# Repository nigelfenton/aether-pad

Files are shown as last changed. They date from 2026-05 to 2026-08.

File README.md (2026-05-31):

# aether_pad

A standalone hardware control surface for [AetherSDR](https://github.com/ten9876/AetherSDR), built on an Arduino Giga R1 WiFi + Display Shield. One self-contained box gives you VFO tuning, mode/volume/band quick-control via a touchscreen, and a CW iambic keyer — all talking to AetherSDR over its TCI WebSocket.

Ops by **G0JKN / W3**.

## Gallery

| Boot — persona menu | Running — TCI persona |
|---|---|
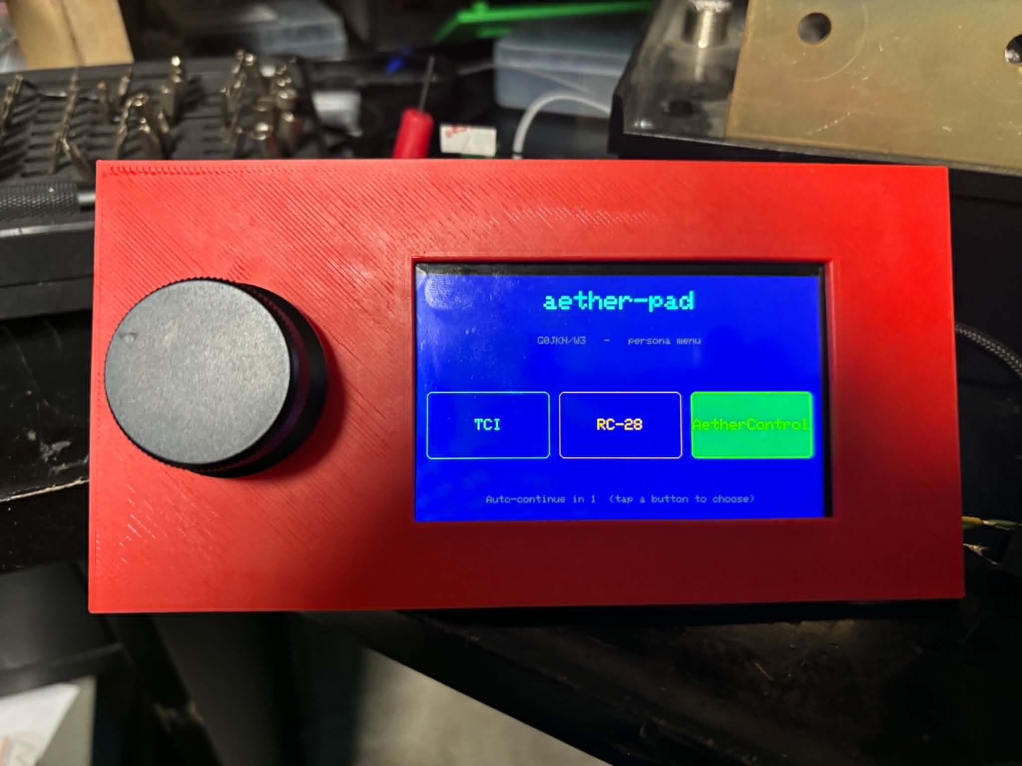
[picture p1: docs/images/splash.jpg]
Splash / persona menu
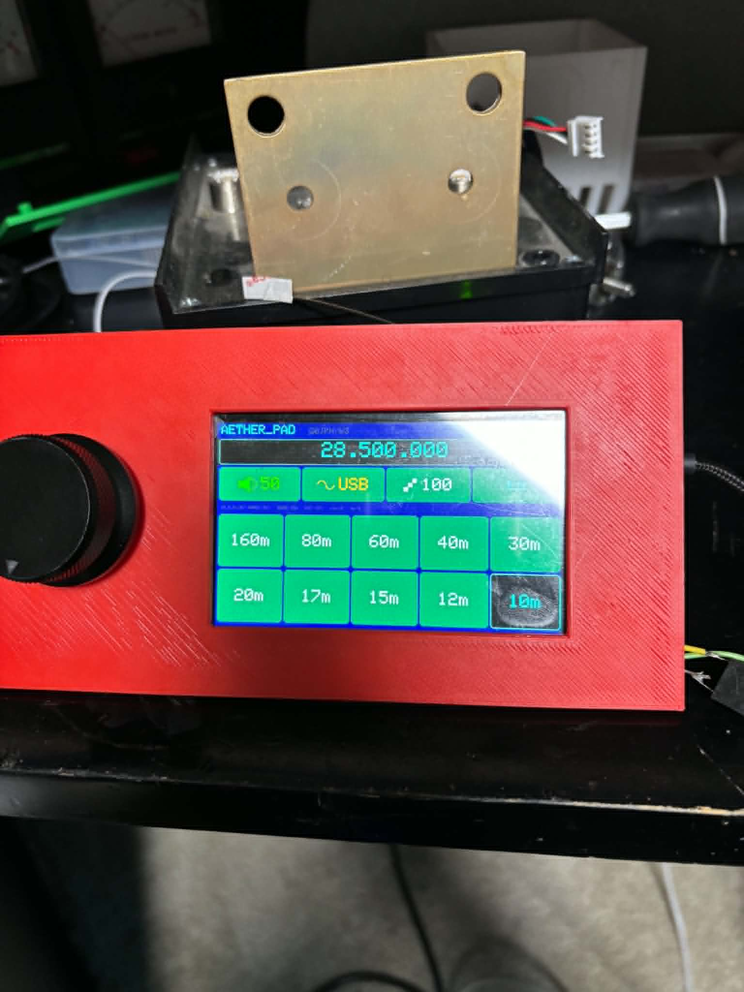
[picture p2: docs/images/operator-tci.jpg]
TCI operator screen on 10 m USB
|  |  |
| Three-button splash (TCI / RC-28 / AetherControl) with 3 s auto-continue. Tap the title bar on any operator screen to re-open this menu. | TCI persona running against AetherSDR — 28.500.000 MHz USB, 10 m band selected. Modal chips arm the encoder for volume / mode / step / keyer in turn. |

## Features

- **Auto-discovery** of AetherSDR on the LAN (UDP probe → unicast reply on port 40002)
- **TCI WebSocket** client — hand-rolled framing, no external libraries beyond stock Arduino WiFi / Display
- **Optical encoder** for VFO tuning with software divider and configurable Hz/click
- **8-button touchscreen** (2 × 4 grid) for VOL / BAND / MODE / VFO ± controls
- **CW iambic keyer** (Mode A or B) — paddles on a 3.5 mm jack, drives the radio's key line through a **GPIO output (D6)** for sub-microsecond, jitter-free timing.  Optional TCI echo (`keyer:0,true|false;`) can be enabled at compile time for AetherSDR-side UI awareness.
- Live status display on the 800 × 480 panel: frequency, mode, volume, band, encoder diagnostics
- Falls back to a hardcoded host IP if discovery times out — works against vanilla AetherSDR (≥ v0.9.5.1) once the responder patch lands

## Hardware

| Part | Notes |
|---|---|
| Arduino Giga R1 WiFi | STM32H747, dual-core M7+M4, USB-C |
| Arduino Giga Display Shield | 800 × 480 panel, GT911 capacitive touch |
| Optical rotary encoder | **LPD3806-600BM-G5-24C** (600 PPR, NPN open-collector, 5–24 V) — runs off Giga 5 V. Autonics E50S-360B (360 PPR, 12–24 V) is also supported as a compile-time alternate via `#define ENCODER_AUTONICS_E50S` near the top of the sketch. |
| 2 × **10 kΩ** resistors | Pull-ups for encoder A (D2) and B (D3) to **3.3 V — never 5 V**. **Required**, not optional — the Giga's internal `INPUT_PULLUP` is too weak to firmly pull these lines HIGH between transistor pulses. |
| Optional: 2 × 10 kΩ resistors | Paddle pull-ups for D4/D5 to 3.3 V if you see noise on long paddle cables. The internal `INPUT_PULLUP` is fine for short paddle leads since a paddle is a passive switch (no leakage current). |
| Optional: 2 × 100 pF caps | D2 / D3 to GND, additional EMI filtering |
| 3.5 mm stereo TRS jack | CW iambic paddle input (or straight key — tip + sleeve only) |
| Encoder supply | 5 V from the Giga **5V** pin if using LPD3806; external 13.8 V (shack rail) if using Autonics E50S — its LED will not light below 12 V |

## Wiring

```
                  Giga R1 WiFi (with Display Shield)
                  ┌─────────────────────────────────┐
                  │                                 │
       Encoder    │                                 │
       ┌────┐     │                                 │
       │ +V ├──── 5 V  (LPD3806 — Giga 5V pin)      │
       │    │     or 13.8 V (Autonics E50S only)    │
       │ 0V ├──── GND ────────── share with Giga    │
       │ A  ├──── D2  (10 kΩ pull-up to 3.3 V)      │
       │ B  ├──── D3  (10 kΩ pull-up to 3.3 V)      │
       └────┘     │                                 │
                  │   pull-ups go to 3.3 V, NEVER   │
                  │   5 V — Giga inputs aren't 5 V  │
                  │   tolerant                      │
                  │                                 │
       Paddle     │                                 │
       (3.5 mm    │                                 │
        TRS)      │                                 │
       ┌────┐     │                                 │
       │ tip├──── D4   (INPUT_PULLUP, dit)          │
       │ rng├──── D5   (INPUT_PULLUP, dah)          │
       │ slv├──── GND                               │
       └────┘     │                                 │
                  │   (straight-key mode discussed, │
                  │   not yet in firmware — for now │
                  │   the iambic state machine will │
                  │   try to interpret a held key)  │
                  │                                 │
       Radio key  │                                 │
                  ├──── D6 → NPN or opto buffer     │
                  │     → radio CW key jack         │
                  │     (see "CW key output" below) │
                  └─────────────────────────────────┘
```

Touch transform `tx = raw_y, ty = 479 - raw_x` is verified for landscape mounting (long axis horizontal, USB-C on the right). If you mount differently, run `tm 0..3` over serial to flip.

## Network

- **WiFi SSID/pass** is hardcoded near the top of `aether_pad.ino` (`tinkerbell` by default — change to your shack network).
- **Discovery** broadcasts `AETHERPAD?` on the local /24 subnet, UDP port 40002. AetherSDR ≥ v0.9.5.1 (with the [TciServer responder patch](https://github.com/nigelfenton/AetherSDR)) replies unicast `AETHERSDR ip=<addr> tci=<port>`.
- **Fallback** after 5 s without a reply: `10.0.0.107:40001`. Override at runtime with `ip <addr>` over serial.

## Install — build and flash the firmware

You'll need an Arduino Giga R1 WiFi, a USB-C cable, and the Display
Shield mounted. Everything below runs in the **Arduino IDE** — no
command-line compiler to wrestle with.

### 1. Install Arduino IDE

Download **Arduino IDE 2.x** from <https://www.arduino.cc/en/software>
and run the installer (Windows / macOS / Linux all supported).

### 2. Add Giga R1 board support

In the IDE:

1. **Tools → Board → Boards Manager…**
2. Search for **`Mbed OS Giga`**
3. Install **Arduino Mbed OS Giga Boards** (latest version)

The board package pulls in the Display Shield libraries automatically:

- `Arduino_H7_Video`
- `Arduino_GigaDisplay_GFX`
- `Arduino_GigaDisplayTouch`

If any are missing, install them via **Sketch → Include Library → Manage Libraries…**

> **⚠️ Pin `Arduino_GigaDisplay_GFX` to 1.0.0.** Version **1.1.0** produces a
> **black screen** — the firmware runs fine (WiFi/TCI all work), but the display
> init breaks against the stable Mbed Giga core's bundled `Arduino_H7_Video` 1.0.
> In **Manage Libraries**, pick **1.0.0** from the version dropdown. If "Update all
> libraries" ever bumps it to 1.1.0, just roll it back to 1.0.0 and re-flash.

### 3. Download the firmware

Either clone the repo:

```sh
git clone https://github.com/nigelfenton/aether-pad.git
```

…or click the green **Code → Download ZIP** button at the top of this
page and unzip it.

### 4. Set your WiFi credentials

Open `aether_pad.ino` in the IDE and edit the two lines near the top:

```cpp
#define WIFI_SSID  "your-network"
#define WIFI_PASS  "your-password"
```

The Giga's WiFi radio is **2.4 GHz only** — point it at your 2.4 GHz SSID,
not a 5 GHz one.

### 5. Plug in the Giga R1

Connect the Giga to your computer with the USB-C cable. After a few
seconds it should appear as a new serial port.

### 6. Pick the board and port

- **Tools → Board → Arduino Mbed OS Giga Boards → Arduino Giga R1**
- **Tools → Port → *<the new port that just appeared>***
  - Windows: typically `COM4` / `COM5` / etc.
  - macOS: `/dev/cu.usbmodem…`
  - Linux: `/dev/ttyACM0`

### 7. Upload

Click the **→** Upload button (top-left of the IDE window). The first
flash takes 1–2 minutes — subsequent ones are quicker. Watch for
**"Done uploading."** at the bottom of the IDE.

### 8. Confirm it booted

Open **Tools → Serial Monitor** and set the baud rate to **115200**
(dropdown bottom-right of the Monitor window). You should see something
like:

```
aether_pad — booting
Build: <date> <time>
WiFi: ........
WiFi connected, IP = 10.0.0.220
Discovery probe → 10.0.0.255
Discovery reply: AETHERSDR ip=10.0.0.107 tci=40001
AetherSDR @ 10.0.0.107:40001
TCI: connecting to 10.0.0.107:40001
TCI: WebSocket handshake OK
```

The touchscreen will light up showing frequency / mode / volume cards
once TCI is connected.

### Troubleshooting

- **No port shows under Tools → Port.** Try a different USB-C cable —
  some are charge-only and carry no data. Unplug, replug, restart the
  IDE if needed.
- **"Board not in selected port" / upload fails.** Double-press the
  Giga's small reset button to force USB bootloader mode, then re-select
  the new port (it will change) and Upload again.
- **WiFi never connects.** Double-check SSID/password spelling. Confirm
  you're on the 2.4 GHz SSID, not 5 GHz.
- **TCI never connects.** In AetherSDR, open **Tools → TCI** and make
  sure the TCI server is enabled on port **40001**. The Giga and the
  AetherSDR host need to be on the same LAN.

## Operating

### Encoder
Spin the knob to tune the VFO. Default step is **100 Hz/click** (fine SSB tuning). Change with `step N` over serial — common values: `step 10`, `step 100`, `step 1000`, `step 10000`. The same step value is shared with the on-screen VFO± buttons.

### Touch buttons (2 × 4 grid)

| Top row | Bottom row |
|---|---|
| `VOL+`  (+5 %) | `VOL−`  (−5 %) |
| `BAND+` (next ham band)¹ | `BAND−` (previous)¹ |
| `MODE+` (next mode in `am sam dsb lsb usb cw digl digu fm dfm spec rtty`) | `MODE−` |
| `VFO+`  (step by current `step`) | `VFO−` (step by current `step`) |

**Long press** (~600 ms) on `VFO+` or `VFO−` cycles the step size:
**100 Hz → 1 kHz → 10 kHz → 100 kHz → wrap.** The current value is shown in the **STEP** card, and the encoder uses the same value, so spinning the knob and tapping the VFO buttons always agree.

¹ *Status note (2026-05-04):* AetherSDR's TCI server doesn't currently implement `band_up`/`band_down` commands, so the BAND± buttons do nothing. Tracked as a known issue.

### CW iambic keyer
Squeeze paddles, send dits/dahs.  Default 25 WPM, Iambic Mode B.  Adjust with `wpm N` and `iambic A|B` over serial.  The Giga handles all element timing in software and drives the radio's key line directly via **D6** — TCI is bypassed entirely for the timing-critical wire path because WebSocket-over-WiFi latency and jitter made dit/dah length audibly unstable even at modest speeds.

> **Optional TCI echo:** if you want AetherSDR to also see the key events for sidetone / UI / metering purposes, define `KEYER_TCI_ECHO 1` at the top of the sketch (or set `-DKEYER_TCI_ECHO=1` at compile time).  The hardware key line is still authoritative for actual radio keying — TCI just gets informational copies.

### CW key output (D6 — default since v0.2)

D6 goes HIGH on key-down and LOW on key-up.  Wire a small buffer between D6 and the radio's CW key jack — never connect the Giga GPIO directly to a key line, since some radios bias the line to +12 V or higher.  Two interface options depending on how isolated you want the Giga from the radio:

Two hardware options depending on how isolated you want the Giga from the radio:

#### Option 1 — NPN buffer (simple, ~£0.10)

Fine for modern transceivers with safe key-line voltages (typically 3–15 V open-circuit, low current). Shares ground with the radio.

```
                                        ┌──────── Radio KEY tip
   Giga D6 ──[ 1 kΩ ]── B (NPN)         │
                        │                C
                        │           ┌────┴────┐
                        E ── GND ───┤   NPN   │
                        (Giga)      │  BC547  │
                                    │ 2N3904  │
                                    │ 2N2222  │
                                    └─────────┘
                                         E ──── GND (shared with radio)
```

- **D6 HIGH** → transistor ON → key line pulled to ground = **key down**
- **D6 LOW**  → transistor OFF → key line floats = **key up**
- Optional 10 kΩ from base to emitter keeps the transistor firmly OFF if D6 ever goes high-impedance.

#### Option 2 — Opto-isolator (proper galvanic isolation, ~£0.50)

Recommended if you're keying a high-power amplifier directly, a tube rig where the key line could float at +30 V or more, or you've ever seen ground-loop or RF-induced weirdness in the shack. The Giga and radio share **no** ground.

```
                                ┌────────── Radio KEY tip
   Giga D6 ──[ 330 Ω ]── A      │
                         │      C
                         │ ┌────┴────┐
                         K │  4N35   │
                         │ │  PC817  │
                         │ │  4N25   │
                         │ └────┬────┘
                         GND    E ──── Radio GND (NOT Giga GND)
                        (Giga)
```

#### Firmware

The keyer's wire path lives in a single `keyerOutput()` function in `aether_pad.ino`.  Default behaviour (since v0.2) is GPIO-only:

```cpp
void keyerOutput(bool down) {
    if (kr.keyDown == down) return;
    kr.keyDown = down;
    digitalWrite(KEY_PIN_OUT, down ? HIGH : LOW);
#if KEYER_TCI_ECHO
    wsSendText(down ? "keyer:0,true;" : "keyer:0,false;");
#endif
    if (down) kr.txCount++;
    uiNeedsRedraw = true;
}
```

The state machine is fully decoupled from the wire — to add MIDI keying, a second hardware output, or anything else, edit only this function.

## Serial commands

All commands at **115200 8-N-1**.

| Command | Effect |
|---|---|
| `?` | Print full state (WiFi/TCI/freq/mode/vol/band/encoder/keyer) |
| `ip <a.b.c.d>` | Override AetherSDR IP and force reconnect |
| `freq <Hz>` | Tune VFO directly |
| `step <Hz>` | Set the shared step size (10 / 100 / 1000 / 10000 typical). Used by both the encoder and the on-screen VFO± buttons. |
| `vol <0..100>` | Set volume directly (AetherSDR audioGain percent — *not* dB) |
| `div <N>` | Set encoder divider (raw quadrature counts per emitted step). Defaults: **40** for LPD3806, **24** for Autonics E50S. |
| `tm 0..3` | Touch transform: 0 = default (verified), 1 = 180°, 2 = raw, 3 = flip-both |
| `wpm <5..100>` | CW keyer speed |
| `iambic A\|B` | Iambic mode (A = current-element-only / no memory; B = opposite-paddle memory, default) |

## Architecture

```
┌─────────────┐  WiFi (UDP 40002)  ┌──────────┐
│  aether_pad ├───── discovery ───►│          │
│   (Giga)    │◄──── reply ────────┤          │
│             │                    │ AetherSDR│
│             │   WS TCI :40001    │          │
│             ├────────────────────►          │
│             │◄────── echoes ─────┤          │
└─┬─┬─┬─┬─────┘                    └──────────┘
  │ │ │ └── touchscreen UI (display + 8 buttons)
  │ │ └──── optical encoder (D2/D3, INT-driven, quadrature)
  │ └────── CW paddle (D4/D5, polled, iambic state machine)
  └──────── serial console (115200, debug + control)
```

The TCI client is hand-rolled WebSocket framing over `WiFiClient`, same minimal approach as [ShackController](https://github.com/nigelfenton/shackcontroller). Outbound frames: `0x81 [len] [payload]` (FIN + text, unmasked — AetherSDR is permissive). Inbound parser handles both masked and unmasked text frames; close frame triggers reconnect. No external WebSocket library needed.

## File map

```
aether_pad/
├── aether_pad.ino       ← all firmware, single sketch
├── README.md            ← this file
├── CASE_DIMENSIONS.md   ← physical case build notes
├── CASE_DIMENSIONS.pdf  ← rendered version of the above
├── md_to_pdf.py         ← helper to regenerate the PDF
├── Aether pad.step      ← Fusion-exported 3D model of the front panel
├── Aether pad.stl       ← latest STL for the slicer
└── lpd3806_panel.dxf    ← 2D sketch of the encoder cutouts (boss + 30 mm PCD)
```

## Future work

- Memory keyer (preprogrammed CQ / 73 / name+QTH macros via `cw_msg:` or `cw_macros:`)
- On-device WPM adjustment via touch (long-press an existing button to enter "CW mode")
- Web UI on port 80 (HTML scaffold is dormant in the source — about 50 lines from working)
- Migrate keyer tick to a hardware timer ISR if loop jitter affects element edges

## Licence

Same as the rest of `shack-experiments` — pick whatever G0JKN's repo licence is.

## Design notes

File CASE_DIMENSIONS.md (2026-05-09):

# aether_pad — case dimensions reference

Single-source dimensional data for designing the Fusion 360 case.
**Verify critical dimensions with calipers before committing extrusions** —
some values below are from datasheets/typicals and may differ slightly from
the actual hardware on your bench.

## 1. Arduino Giga R1 WiFi (base board)

| Property | Value |
|---|---|
| PCB outline | 101.52 × 53.3 mm |
| PCB thickness | 1.6 mm |
| Form factor | Arduino Mega-compatible footprint |
| Mounting holes | 4 × M3 (Mega-compatible) — **NOT used in this build** (Giga hangs from Shield via stacked headers) |
| USB-C connector | top edge (long side), centred near corner |
| Power jack | top edge, barrel 2.1mm centre-positive (5.5mm OD), accepts 7-24 V |
| Headers | 4 stacks (digital, analog, power, SDA/SCL) — 8.5 mm tall |
| Stack height to shield top of headers | ~14 mm above PCB |

**Verify:** mounting hole XY positions relative to PCB corner (0,0).

## 2. Giga Display Shield (mates on top of Giga)

| Property | Value |
|---|---|
| Shield PCB outline | **106 × 80 mm** (measured 2026-05-03) |
| Display module (LCD + cover glass, visible extent) | **100 × 58 mm** (measured 2026-05-03) |
| Active pixel area | 84 × 50.5 mm (800 × 480 px, 5:3 aspect, inside the display module) |
| Active display offset from PCB **left edge** | **6.3 mm** (measured) |
| Active display offset from PCB **right edge** | 15.7 mm (computed: 106 − 6.3 − 84) |
| Active display offset from PCB **top edge** | **16 mm** (measured 2026-05-03) |
| Active display offset from PCB **bottom edge** | **13 mm** (measured 2026-05-03) |
| Active display height (computed) | 51 mm (80 − 16 − 13, matches 50.5 mm spec) |
| Vertical bias of active within PCB | ~1.5 mm **toward the bottom** |
| Mounting holes | 4 corners, M3, **5 × 5 mm inset** from each PCB edge (measured) |
| **Mounting hole pattern (centre-to-centre)** | **96 × 70 mm** — these are the only case mounting bosses needed |
| **Front-panel window cutout** | **100 × 58 mm** to expose the full display module |
| USB-C connector (on shield) | edge OPPOSITE the 6.3 mm-margin side (right edge in default orientation) |
| Total stack height (Giga + headers + shield) | ~22 mm from Giga PCB bottom to shield top surface |

**IMPORTANT for assembly:** mount the shield so its **6.3 mm-margin edge faces the encoder**. The opposite edge has 15.7 mm of dead PCB beyond the active area, and orienting that side toward the encoder would cost ~9.4 mm of clearance. The flip-mode rotation preserves this — when the top rotates 180°, the 6.3 mm edge still faces the (now opposite-side) knob.

## 3. Autonics E50S8G5-360B-G24N optical encoder

| Property | Value |
|---|---|
| Body diameter | 50 mm |
| Body length (behind panel) | **38.6 mm** (measured 2026-05-03) |
| Total length incl. shaft | ~52 mm |
| Shaft diameter | 8 mm |
| Shaft length | ~13 mm beyond body |
| Mounting | 3 × M3 screws on a **40 mm PCD** (20 mm radius), on the front face — measured |
| Panel mount hole | 32 mm centre clearance (to clear shaft + boss) |
| Wiring | 5-wire pigtail: A, B, Z, +V (12-24V), 0V |
| Operating voltage | 12-24 V DC (uses 13.8 V from shack rail) |
| PPR | 360 |

**For the recessed-knob design:**
- Panel cutout: 32 mm hole for shaft + boss, 3 × M3 tapped or clearance holes on **40 mm PCD**
- Behind-panel clearance needed: **38.6 mm minimum depth** (encoder body length), 50+ mm diameter
- Knob hollow cavity: 52 mm ID, 38.6+ mm deep so it clears the encoder body
- Knob outer dimensions: ~55-60 mm OD typical, 10-15 mm tall above panel
- Knob coupling: 8 mm bore, M3 grub screw onto shaft flat

## 4. CW paddle jack — 3.5 mm TRS, panel mount

| Property | Value |
|---|---|
| Panel hole | 6 mm |
| Body length behind panel | ~15-20 mm (varies by part) |
| Mounting | nut + lock washer on threaded barrel |
| Wiring | tip = dit (D4), ring = dah (D5), sleeve = GND |

## 5. Power entry — **Anderson PowerPole, daisy-chainable**

12 VDC in via Anderson PowerPoles. **Two pairs** (red+black, red+black) on the
rear panel — one pair is the feed in, the second pair allows daisy-chaining the
next shack module on the same supply. Dimensions confirmed against the parts on
hand.

| Property | Value |
|---|---|
| Housing size (single PP15/30/45) | 7.87 × 11.94 × 16.26 mm |
| Red+black pair (clipped together) | 15.75 × 11.94 × 16.26 mm |
| **Cutout per pair** | **16.3 × 18.4 mm** (snug fit on housing, ~2.7 mm clearance for retainer wall) |
| **Retainer sleeve** | **24.6 mm long, 3 mm wall thickness** around the opening — 3D-printed, extends into the case interior |
| Total clearance behind panel | ~25 mm for housing + wire bend |
| Wiring | Wire both pairs in parallel internally (same +/− nodes) so daisy-chain just passes through |

Encoder needs 12-24 V (uses 13.8 V from shack rail); Giga accepts 7-24 V. Single 12 V supply works for both.

**Cutout layout — TBD, two options:**
- **(a)** Two separate 16.3 × 18.4 cutouts with 5-10 mm gap between → flexible, two independent retainers
- **(b)** One combined 16.3 × ~37.3 mm cutout → single retainer block, more compact

Place on rear panel, central horizontally, ~10 mm up from the case base for cable clearance.

## 6. Combined stack — case envelope (symmetric flip-mode, locked)

Sloped desktop unit, screen on the right of the front panel, encoder + recessed
knob on the left, no side cutouts (no USB-C side access — open the case for
reflashing using a USB-C extension cable).

```
       ┌────────────────────────────────────────┐
      ╱                                         ╲      ← front panel plane
     ╱   ⬡        ┌──────────────────┐         ╲    (sloped 10-15° back)
    ╱   knob      │   Display 84×50  │   15mm  ╲
   ╱   recess     │   active area    │   margin ╲
  ╱   (left)      └──────────────────┘           ╲
 └────────────────────────────────────────────────┘   ← base
        │←──────── ~175 mm total width ────────→│
```

Symmetric design — knob and screen window mirror about the case centreline.
Hardware (Giga + Shield + encoder) lives in the **removable top half**, so
rotating the top 180° physically moves them to the opposite side; the base
stays put with rear connectors fixed in position.

**Front panel layout (default orientation, encoder on left):**

```
 ┌────────────────────────────────────────────────────────┐
 │                                                        │
 │  ┌──────┐                          ┌─────────────────┐ │
 │  │      │                          │                 │ │
 │  │ knob │←────── 20 mm gap ────→│  display window │ │
 │  │ Ø60  │                          │   100 × 58 mm   │ │
 │  │      │                          │                 │ │
 │  └──────┘                          └─────────────────┘ │
 │                                                        │
 └────────────────────────────────────────────────────────┘
   │←15→│←──60──→│←─── 20 ───→│←────── 100 ──────→│←15→│
   │←──── 60 ────→│             │←──── 100 ────→│
   │  knob centre at -60       │ window centre at +40
   │←──────────── 210 mm internal ────────────→│
```

| Property | Value |
|---|---|
| Margin: knob outer edge to left wall | 15 mm |
| Margin: window outer edge to right wall | 15 mm |
| Gap between knob and window | **20 mm** (gives 26.7 mm encoder-PCB clearance) |
| Knob centre offset from case centreline | 60 mm (left in default) |
| Window centre offset from case centreline | 40 mm (right in default) |
| Top + bottom margins to window | **17 mm** each (gives ~5 mm PCB clearance) |

**Internal envelope (locked):**

| Dimension | Value | Driver |
|---|---|---|
| Width  | **210 mm** | symmetric about centreline, 60+30+15 each side, 20 gap, screen window 100 |
| Height (perp to slope) | **92 mm** | window 58 + 17 top + 17 bottom margins (PCB ~5 mm clearance) |
| **Slope angle from vertical** | **15°** | nearly upright, compact, comfortable bench viewing |
| **Total interior depth (front to back at base)** | **68.8 mm** | wedge 23.8 + box 45 (box bumped to clear deeper-than-spec encoder body) |
| **Total interior height (vertical)** | **88.9 mm** | = 92 × cos(15°) |

**Side profile (right trapezoid, looking from the right):**

```
       A─────────────────────────────B    A = (23.8, 88.9) — wedge top
      ╱│                             │    B = (68.8, 88.9) — back top
     ╱ │                             │    C = (68.8, 0)    — back bottom
    ╱  │        case                 │    D = (0, 0)       — front bottom
   ╱   │        interior             │
  ╱    │                             │    Slope D→A: 92 mm @ 15° from vertical
 ╱     │                             │    Top   A→B: 45 mm flat (box top)
╱      │                             │    Back  B→C: 88.9 mm vertical
└──────┴─────────────────────────────┘    Base  C→D: 68.8 mm horizontal
       ←── 23.8 ──→←──── 45 ────→
        wedge       box
```

External envelope with 3 mm walls: **216 W × 75 D × 95 H mm**.

**Component placement inside (verified, no 3D conflicts):**

| Component | Front-face / mount position | Extent into case |
|---|---|---|
| Display Shield + Giga stack | parallel to slope, mounted to fascia | 22 mm perpendicular to slope |
| Encoder body | slope midpoint (X=11.9, Y=44.4), Z=−60 from centreline | 38.6 mm along slope normal → back face at (X=49.2, Y=34.4); back-top corner at (X=55.7, Y=58.6) |
| PowerPole sleeves (×2) | back wall, centred Z, centred Y | 24.6 mm into case (X from 44.2 to 68.8) |
| Paddle jack | back wall, centred Z | ~15-20 mm sleeve |
| Flip switch | back wall, near corner | tiny |

The encoder body and PowerPole sleeves overlap in side view (both at similar X), but they're separated in the case-width (Z) direction by ~26 mm — encoder at Z=−60, PowerPoles centred at Z=0. No 3D conflict.

**Encoder back-top to back wall: 13.1 mm clearance** — enough for the 5-wire pigtail strain relief and a 90° cable bend toward the base's central connector.

**Box top (the 45 mm flat region between wedge apex and back wall)** is useful internal volume for routing the cable between the rotating fascia and the base's rear connectors.

**PCB position note:** because the active display is biased ~1.5 mm toward the bottom of the PCB, when you align the display module with the case-centred window, the PCB itself sits ~1.5 mm UPWARD of the case vertical centre. Standoff heights need to account for this if you're putting the PCB on a centred mount.

**After 180° top rotation:** knob ends up on the right at +60, window on the left at −40, all margins preserved. Identical clearances in both orientations.

### Front panel artwork (default orientation, encoder on left)

Front panel size: **210 × 92 mm** (in the plane of the slope). Origin at lower-left, X right, Y up.

**Visible features (cuts through the front face):**

| Feature | Position | Size / type |
|---|---|---|
| Screen window cutout | centre (145, 46) | 100 × 58 mm rectangle, 2-3 mm corner radius |
| Knob shaft clearance | centre (45, 46) | Ø32 mm round cutout |
| Encoder mount #1 (12 o'clock) | (45.0, 66.0) | Ø3.5 mm M3 clearance |
| Encoder mount #2 (4 o'clock) | (62.3, 36.0) | Ø3.5 mm M3 clearance |
| Encoder mount #3 (8 o'clock) | (27.7, 36.0) | Ø3.5 mm M3 clearance |

The 3 encoder mounting holes are 120° apart on a **Ø40 mm PCD** (20 mm radius), measured 2026-05-03. The orientation shown puts one hole at 12 o'clock — rotate the trio if the encoder pigtail needs clearance elsewhere.

**Internal-only features (back side of fascia, no through-holes):**

| Feature | Position | Type |
|---|---|---|
| Shield mounting standoff | (101.7, 82.5) | M3 self-tap or threaded insert |
| Shield mounting standoff | (197.7, 82.5) | (4 corners of shield PCB) |
| Shield mounting standoff | (101.7, 12.5) | |
| Shield mounting standoff | (197.7, 12.5) | |

Standoff heights set the gap between fascia inner surface and PCB top — typically 5 mm to clear the LCD module thickness.

**No screws on the front face** — the fascia attaches via an inner skirt + side screws (see §7).

## 7. Two-half case construction (the rotating-top design)

The case is split horizontally:

- **BASE** = standard, fixed orientation. Rear panel with connectors. Sits on bench. Side walls have screw-engagement holes for the fascia skirt.
- **TOP (fascia)** = removable, contains all active hardware (Giga + Display Shield + encoder + their wiring). Has an **inner skirt** on the underside that drops into the base interior; held captive by **side screws** through the base side walls into the skirt. No screws visible on the front face.

**To flip for friend-mode:** power off, undo side screws, lift top off, unplug internal cable, rotate top 180°, reseat, replug, rescrew, set the rear flip switch, power up. ~60 seconds.

**Mechanical requirements (preserves flip-mode rotational symmetry):**
- Inner skirt outline: **rectangular, centred on the case**, slightly smaller than the base interior (~2 mm under-size all round for a snug locate fit). Skirt depth into base ~10-15 mm.
- Side screws on **mirrored positions left and right** at the same height — typically 2 per side at top and bottom of the engagement region.
- Internal cable connector (5 wires: +12V, GND, paddle dit, paddle dah, flip switch) located on the **case centreline** so both orientations reach it.
- Rear connectors stay on the base, position-independent of top rotation.
- Top must be wide and deep enough internally to hold the hardware in either orientation without collision (drives the 210 × 92 × 53.8 mm interior dimensions in §6).

## 8. Firmware changes needed for flip-mode

Add to `aether_pad.ino`:

```cpp
const int FLIP_PIN = 6;            // rear switch → D6, INPUT_PULLUP
bool flipped = false;              // set in setup() from FLIP_PIN

// In setup(), after pinMode/INPUT_PULLUP on FLIP_PIN:
flipped = (digitalRead(FLIP_PIN) == LOW);
tft.setRotation(flipped ? 3 : 1);
touchMode = flipped ? 1 : 0;       // mode 1 = 180° from default

// In encISR, conditionally invert direction:
encRaw += (flipped ? -1 : +1) * QUAD[(encLast << 2) | now];
```

That's it — ~5 lines plus a pinMode in setup.

## 9. USB-C access — **decided: no external cutout**

No external USB-C access on the case. For reflashing, open the case (or use a
USB-C extension cable threaded through one of the rear cutouts temporarily).
This keeps the side panels clean, simplifies symmetry for flip-mode, and avoids
needing a panel-mount USB-C extension.

## 10. Rear panel — connector layout summary

All external connectors live on the rear panel. Suggested layout (left to right
when viewed from the back):

```
 ┌──────────────────────────────────────────────────┐
 │                                                  │
 │  [PP×4 cutout]    [3.5mm jack]    [flip switch]  │
 │   32×17 mm         ⌀6 mm           if symmetric  │
 │                                                  │
 │  [vent slots]                                    │
 │                                                  │
 └──────────────────────────────────────────────────┘
```

| Connector | Position | Cutout |
|---|---|---|
| PowerPole pair × 2 | rear panel, **two separate cutouts** with ~5-10 mm gap between | 16.3 × 18.4 mm each (24.6 mm sleeves into case) |
| 3.5 mm CW paddle TRS | rear panel, central | ⌀6 mm circular |
| Flip-mode switch | rear panel, near corner | small SPST toggle, ~6 mm hole |
| Ventilation slots | rear panel, lower portion | array of slots, ~10% open area |

## 10. Ventilation

The Giga R1 runs warm (STM32H747 dual-core), especially with WiFi active. Recommend:

- Slot pattern on bottom panel under the Giga
- Slot pattern on rear panel (or wherever the convection exit is on a sloped enclosure)
- 3-5 mm wall-to-PCB-bottom standoff so air can flow under

Total open area ~10% of the relevant face is plenty for passive cooling.

---

## TODO before final case design

- [x] ~~Caliper-verify Giga mounting hole XY pattern~~ → not needed; Giga hangs from Shield via headers. Optional printed support clips between Giga and Shield to take bending load off the header pins.
- [ ] Caliper-verify shield active-display XY relative to mounting holes
- [ ] Caliper-verify shield mic position (if grille wanted on top of case)
- [x] ~~Decide power entry style~~ → Anderson PowerPole, 16.3 × 18.4 mm per pair, 24.6 mm sleeve, 3 mm wall
- [x] ~~Decide USB-C strategy~~ → no external access, open case for reflash
- [x] ~~Decide screen-edge to side-of-case margin~~ → 15 mm right side
- [x] ~~Decide encoder offset~~ → 60 mm from case centreline (default = left), vertically centred
- [x] ~~Decide PowerPole cutout layout~~ → two separate 16.3 × 18.4 cutouts, ~5-10 mm gap between
- [x] ~~Confirm knob OD~~ → 60 mm assumed (verify when knob is sourced/printed)
- [x] ~~Commit to flip-mode~~ → YES, via removable+rotatable top half (see §7)
- [x] ~~Verify shield active display offset within PCB~~ → 6.3 mm from left, 13 mm from top
- [x] ~~Verify display module size~~ → 100 × 58 mm (front-panel window)
- [x] ~~Lock case slope angle~~ → **15° from vertical** (interior 68.8 mm deep, 88.9 mm tall, wedge front + 45 mm box back)
- [x] ~~Caliper-verify encoder body depth and mounting PCD~~ → 38.6 mm deep (was 30 in datasheet typical), 40 mm PCD (was 30) — measured 2026-05-03
- [x] ~~Source or design the recessed knob~~ → 3D-print in 2 parts with pause-print at the steel-ball layer to embed weight (Nigel's design). Confirm final OD when designed — affects case width if >60 mm.
- [ ] Source PowerPole panel-mount retainer (commercial or 3D-printed)
- [ ] Add flip-pin handling to firmware (~5 line change, waits until physical switch is wired)
- [ ] Wire the flip-mode switch on rear panel (D6, INPUT_PULLUP)

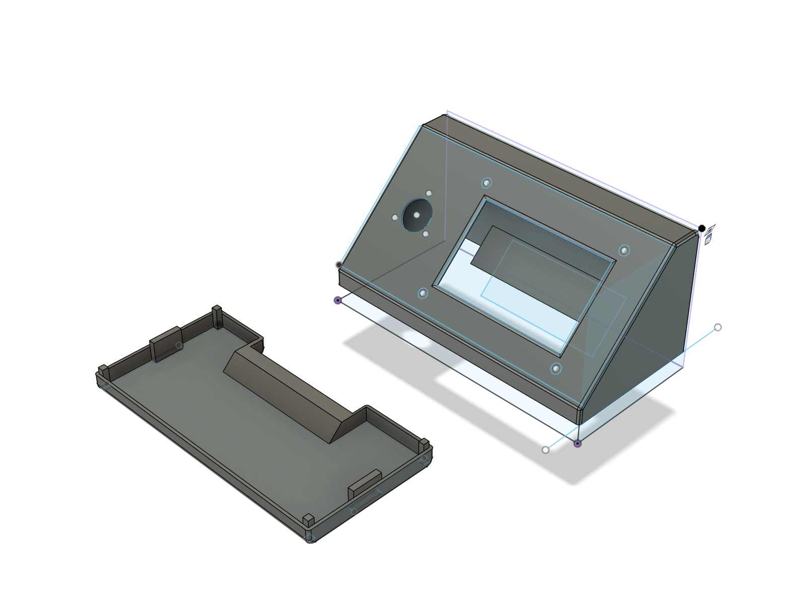
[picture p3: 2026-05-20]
case/aether pad case split.png

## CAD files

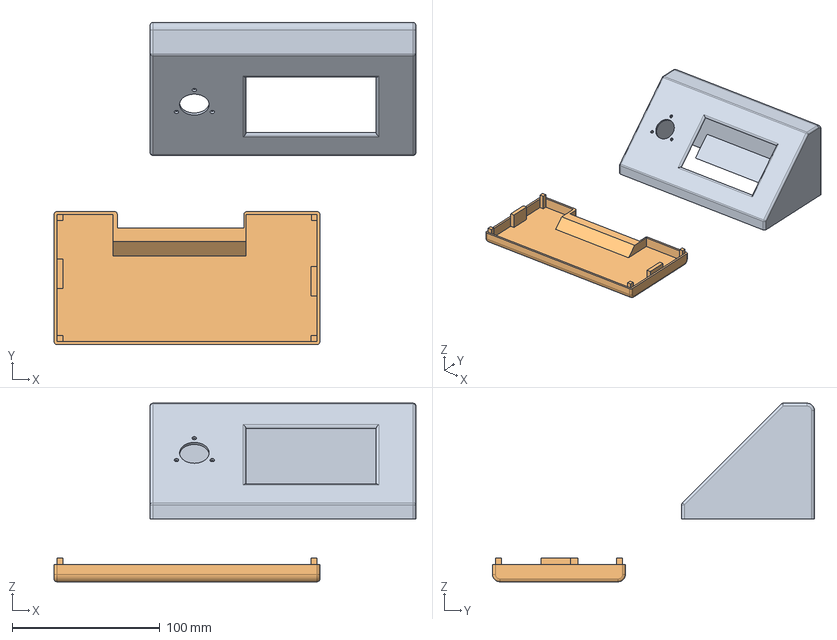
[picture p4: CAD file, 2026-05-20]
case/aether pad case split.step
245.0 x 217.9 x 120.9 mm

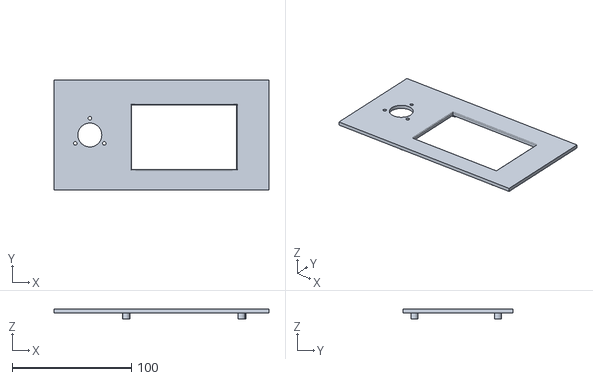
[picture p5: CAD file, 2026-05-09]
case/Aether pad 180.stl
180.0 x 92.0 x 8.00

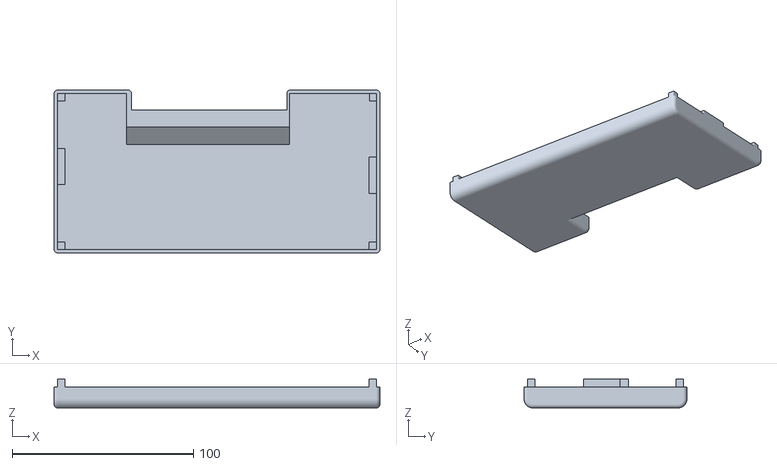
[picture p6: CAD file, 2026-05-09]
case/Body4.stl
180.0 x 90.0 x 16.0

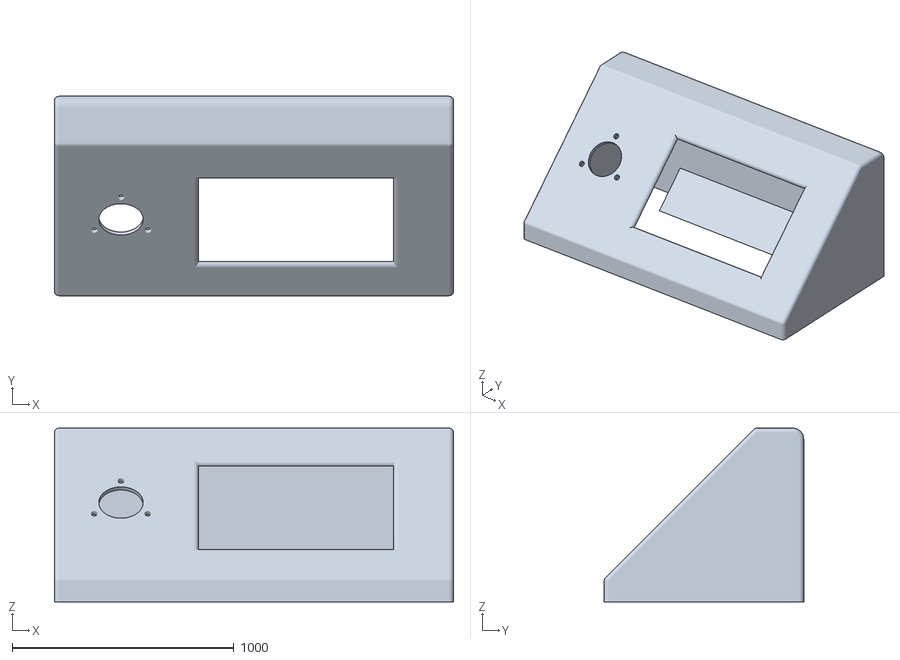
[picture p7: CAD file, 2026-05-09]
case/Aether pad top.stl
1800.0 x 900.0 x 783.8

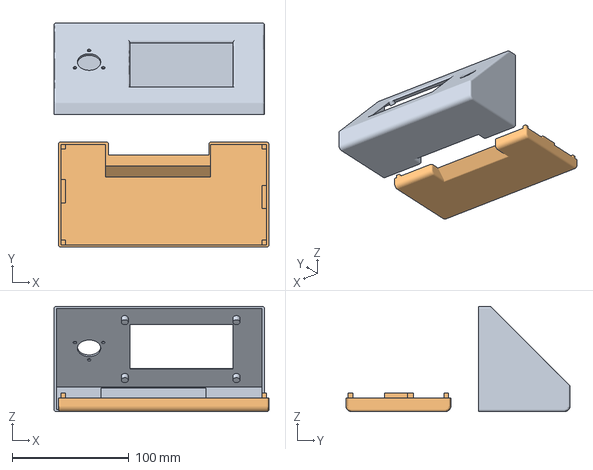
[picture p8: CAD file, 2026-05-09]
case/Body1.3mf
183.8 x 191.9 x 90.0 mm
Body1.stl
Body4.stl

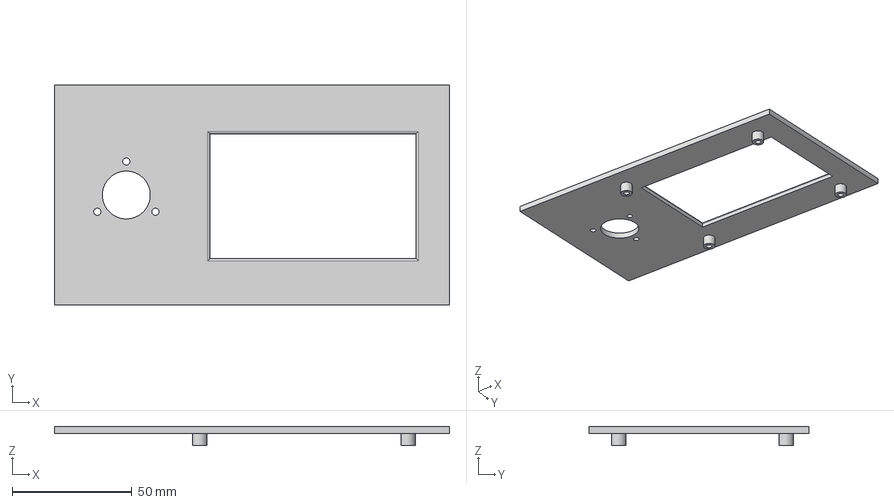
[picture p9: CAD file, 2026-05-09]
case/Aether pad.step
165.0 x 92.0 x 8.00 mm

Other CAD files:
case/aether pad case.stl
case/ 1.stl
case/Aether pad.stl
case/Body1.stl
case/aether pad case split.f3d
case/aether pad case split.stl

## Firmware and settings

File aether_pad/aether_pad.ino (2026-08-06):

// ###########################################################################
// #                                                                         #
// #   BUILD MARKER:  SPLASH / PERSONA MENU v5  (boot-phase status strip)    #
// #                                                                         #
// #   Boot -> splash screen with 3 persona buttons (TCI / RC-28 /           #
// #   AetherControl) and a 3 s auto-continue (defaults to TCI for now).    #
// #   Tap any button on splash = enter that persona's operator screen.     #
// #   Tap the title bar on the operator screen = re-open the splash as a   #
// #   menu (auto-continues back to current persona on no-tap).             #
// #   10m tile long-press still enters TEST mode (unchanged).               #
// #                                                                         #
// ###########################################################################

/*
 * aether_pad.ino
 * Standalone AetherSDR control surface — Arduino Giga R1 WiFi + Display Shield
 * G0JKN/W3 — shack-experiments
 *
 * Hardware
 *   Arduino Giga R1 WiFi
 *   Giga Display Shield (800×480 landscape, GT911 touch, USB-C on right edge)
 *   Optical encoder (NPN open-collector — pick type below via #define):
 *     LPD3806-600BM-G5-24C : 600 PPR, 5-24 V supply  → power from Giga 5 V pin
 *     Autonics E50S-360B   : 360 PPR, 12-24 V supply → power from shack 13.8 V railyou stiring up trouble?
 
 *     A → D2  (10 kΩ external pull-up to 3.3 V — Giga INPUT_PULLUP alone is too weak)
 *     B → D3  (10 kΩ external pull-up to 3.3 V — Giga INPUT_PULLUP alone is too weak)
 *     +V → 5 V (LPD3806) or external 13.8 V (Autonics — LED needs 12-24 V)
 *     0 V → shared GND with Giga
 *
 *   3.5 mm stereo TRS jack for CW iambic paddle:
 *     tip    (dit) → D4  (INPUT_PULLUP, paddle closes to GND)
 *     ring   (dah) → D5  (INPUT_PULLUP, paddle closes to GND)
 *     sleeve       → Giga GND
 *   Straight-key operators wire their key directly to the radio's CW
 *   jack — bypasses the pad/WiFi entirely for sub-ms keying response.
 *
 * UI (800×480 landscape) — modal-encoder design (redesigned 2026-05-07)
 *   Title bar : "AETHER_PAD G0JKN/W3" + host info + LIVE/.../SCAN pill
 *   Freq      : big centred VFO frequency — TAP to arm encoder for VFO
 *   Chips     : three modal status cards, TAP any to arm the encoder
 *                  [ VOLUME ]   [ MODE ]   [ STEP ]
 *                The currently-armed chip glows cyan. The encoder always
 *                works; what it controls follows the last chip you tapped.
 *   Status    : thin strip showing current band, encoder target, debug info
 *   Bands     : 10 direct band tiles in 5×2 grid — TAP to jump to band's
 *                last-known frequency (RAM band-stack, sensible defaults).
 *                Active band (containing the current VFO) glows cyan.
 *                  [160m][80m][40m][20m][15m]
 *                  [ 10m][ 6m][ 2m][70cm][23cm]
 *   Encoder   : modal — VFO/VOL/MODE/STEP per active chip. Default boot
 *                target is VFO so out-of-the-box behaviour is unchanged.
 *
 * Network
 *   WiFi    : tinkerbell
 *   Discovery (outbound, find AetherSDR):
 *              UDP probe "AETHERPAD?" → port 40002, listens for unicast reply
 *              "AETHERSDR ip=<addr> tci=<port>". Falls back to 10.0.0.107:40001
 *              after 5 s if no responder is on the LAN yet.
 *   Discovery (inbound, advertise self):
 *              mDNS / DNS-SD under _tci._tcp.local per
 *              github.com/ten9876/AetherSDR/docs/tci-discovery.md.  Class
 *              "controller", model "aether-pad".  SRV port is 0 — aether_pad
 *              is a TCI client, not a server.  See mdns_tci.h/.cpp.
 *   Control : TCI WebSocket client to ws://<host>:<port>/ — hand-rolled framing
 *             (same minimal approach as ShackController firmware).
 *
 * Serial commands (115200 baud)
 *   ?              Show state
 *   ip <a.b.c.d>   Override AetherSDR IP and reconnect
 *   div NN         Set encoder divider (raw counts per VFO step), default 24
 *   step NN        Set encoder VFO step in Hz, default 100 (buttons fixed 10 kHz)
 *   vol N          Set volume directly (0-100, AetherSDR audioGain percent)
 *   freq NNN       Set frequency directly (Hz)
 *   tm 0..3        Touch: 0=default (verified), 1=180°, 2=raw, 3=flip-both
 *   wpm N          CW keyer speed (5..100 WPM, default 25)
 *   iambic A|B     Iambic mode (default B — opposite-paddle memory)
 */

#include <WiFi.h>
#include <WiFiUdp.h>
#include "Arduino_H7_Video.h"
#include "Arduino_GigaDisplay_GFX.h"
#include "Arduino_GigaDisplayTouch.h"
#include "mdns_tci.h"
#include "rc28_hid.h"

// USB HID device — impersonates Icom RC-28 for in-bench testing of
// AetherSDR's IcomRC28Parser (PR ten9876/AetherSDR#2870). Enumerated at
// boot; reports are only sent when the operator has entered TEST mode
// from the touchscreen (long-press on the 10m band tile). NORMAL mode
// leaves the device enumerated but silent so the host sees no spurious
// tuning events while aether-pad is in everyday TCI use.
AetherPad::Rc28Hid rc28;

// ---------------------------------------------------------------------------
// Build identification — printed at boot and in `?` output so you can
// confirm the running firmware matches your latest reflash.  __DATE__ and
// __TIME__ are filled in by the compiler at build time.
// ---------------------------------------------------------------------------
#define BUILD_TAG  __DATE__ " " __TIME__

// ---------------------------------------------------------------------------
// Encoder type — pick ONE, comment out the other
// ---------------------------------------------------------------------------
#define ENCODER_LPD3806            // 600 PPR, 5-24 V (small 38mm body, runs off Giga 5 V)
//#define ENCODER_AUTONICS_E50S    // 360 PPR, 12-24 V (needs shack 13.8 V rail)

#if defined(ENCODER_LPD3806)
  const char* ENC_NAME        = "LPD3806-600BM (600 PPR, 5-24 V)";
  const int   ENC_DIV_DEFAULT = 40;   // 600 PPR × 40 ≈ same feel as Autonics × 24
#elif defined(ENCODER_AUTONICS_E50S)
  const char* ENC_NAME        = "Autonics E50S-360B (360 PPR, 12-24 V)";
  const int   ENC_DIV_DEFAULT = 24;
#else
  #error "Pick an encoder: define ENCODER_LPD3806 or ENCODER_AUTONICS_E50S"
#endif

// ---------------------------------------------------------------------------
// Config
// ---------------------------------------------------------------------------
const char* WIFI_SSID = "tinkerbell";
const char* WIFI_PASS = "disneybell";

const uint16_t  DISCOVERY_PORT      = 40002;
const char*     DISCOVERY_PROBE     = "AETHERPAD?";
const uint32_t  DISCOVERY_INTERVAL  = 2000;   // ms between probes while not connected
const uint32_t  DISCOVERY_FALLBACK  = 5000;   // ms before falling back to hardcoded IP
// Used only if the UDP discovery probe goes unanswered. ⚠ Both of these had
// drifted: .107 is a pre-DHCP address aurora13 no longer holds, and AetherSDR
// listens on 50001, not the 40001 in the older docs. Verified live 2026-08-05 —
// ws://10.0.0.104:50001 answers a TCI `start;` with vfo_limits/trx_count.
// ⚠ DHCP moves aurora13, so treat this as a hint, not a fact: discovery is the
// real mechanism and this is just what to try when nobody replies.
IPAddress       FALLBACK_HOST(10, 0, 0, 104);
const uint16_t  FALLBACK_PORT       = 50001;

// VFO / encoder
const int  ENC_PIN_A = 2;
const int  ENC_PIN_B = 3;
int        encDivider     = ENC_DIV_DEFAULT;  // raw quadrature counts per emitted step
long       vfoStepHz      = 100;   // step per emitted encoder click & per VFO± tap (long-press cycles)
const unsigned long LONG_PRESS_MS = 600;   // touch-hold duration that triggers long-press

// CW iambic keyer — paddle pin assignment matches Nigel's paddle wiring
// (tip→dah, ring→dit) so left=dit, right=dah feels natural. If your
// paddle is wired the other way, swap KEY_PIN_DIT and KEY_PIN_DAH.
// Straight-key operators wire their key directly to the radio's CW
// jack instead of through the pad — sub-ms response and no WiFi-
// dependence (tested 2026-05-08: straight key over WiFi was unusable).
const int  KEY_PIN_DIT = 5;     // paddle ring → D5 (INPUT_PULLUP, closes to GND)
const int  KEY_PIN_DAH = 4;     // paddle tip  → D4 (INPUT_PULLUP, closes to GND)
const int  KEY_PIN_OUT = 6;     // hardware key output → D6 (active HIGH)
                                // Wire D6 to a 2N3904 base via 1 kΩ, emitter to GND,
                                // collector to the radio's CW key jack tip.  D6 HIGH
                                // saturates the transistor, pulling the key line to
                                // GND (= key down).  Optocoupler (PC817 / 4N25) is
                                // safer if the radio's key input shares ground with
                                // its high-voltage rails — see README for circuit.
int        cwWpm       = 25;    // 5-100 WPM, advertised to AetherSDR via cw_keyer_speed
char       iambicMode  = 'B';   // 'A' or 'B'; B is the most common (memory of opposite paddle)

// Mode rotation
const char* MODES[] = {"am","sam","dsb","lsb","usb","cw","digl","digu","fm","dfm","spec","rtty"};
const int   N_MODES = 12;

// Volume range — AetherSDR's TCI volume is per-slice audioGain, 0-100 percent
// (see TciProtocol.cpp:741). Step matches AetherSDR's own UI click increment.
const int VOL_MIN  = 0;
const int VOL_MAX  = 100;
const int VOL_STEP = 5;

// VFO step rotation — used when encoder is armed for STEP target
const long STEP_CYCLE[] = {10L, 100L, 1000L, 10000L, 100000L};
const int  N_STEPS = 5;

// ---------------------------------------------------------------------------
// Modal encoder target — the encoder always works; what it controls depends
// on which on-screen chip the user last tapped. Default after boot is VFO so
// the device behaves as before until a chip is touched.
// ---------------------------------------------------------------------------
enum EncoderTarget : uint8_t {
    TGT_VFO = 0,
    TGT_VOL,
    TGT_MODE,
    TGT_STEP,
    TGT_KEYER       // CW keyer WPM
};
EncoderTarget encTarget = TGT_VFO;

// Rate-limit non-VFO encoder dispatches. Smooth optical encoders have no
// detents, so a quick flick can spit out 5-10 steps before the operator
// reacts. For VFO that's desirable (fast tuning); for STEP/MODE/VOL/WPM
// it makes the chip feel out of control. 400 ms feels deliberate without
// being sluggish; combined with ENC_NONVFO_DIV_MULT it forces the operator
// to commit to a real rotation before each emission.
const unsigned long ENC_NONVFO_MIN_MS    = 400;
// Multiplier on encDivider when armed for non-VFO targets — requires
// ENC_NONVFO_DIV_MULT × encDivider raw counts per emitted step. With the
// default LPD3806 divider of 40, that's 80 counts per step → roughly half
// a turn of the knob. Plenty of feedback before each change.
const int           ENC_NONVFO_DIV_MULT  = 2;

// ---------------------------------------------------------------------------
// Band stack — one entry per band tile shown on the bottom of the screen.
// `lastHz` is the most recent frequency the operator was on within that band;
// it's seeded with a sensible centre and gets updated whenever the VFO moves
// inside the band. RAM-only for now; persistence (KVStore on Giga) is a TODO.
// ---------------------------------------------------------------------------
struct BandEntry {
    const char* name;
    long        loHz;     // band edge low (used for VFO→band tracking)
    long        hiHz;     // band edge high
    long        lastHz;   // last operator frequency within this band
};
// VFO limits. Declared HERE, above every user — the TCI parse validates against
// them, the encoder clamps to them, and the serial console checks them.
//
// The old ceiling was 60 MHz, hardcoded in three separate places, and it made
// the pad unable to reach a VHF/UHF radio at all: an IC-9700 lives ENTIRELY
// above it (2 m / 70 cm / 23 cm), so the knob stopped dead at 60.000 MHz.
//
// 1.3 GHz is the 9700's 23 cm top edge. NB `long` is 32-bit on the Giga —
// signed max is 2147.5 MHz, so this fits with ~847 MHz to spare, but a future
// ceiling above ~2.1 GHz would need int64_t here AND in st.freqHz, at the
// atol() in the TCI parse, and in formatFreq().
const long VFO_MIN_HZ =      100000L;   // 100 kHz
const long VFO_MAX_HZ = 1300000000L;    // 1.3 GHz — IC-9700 23 cm top edge

BandEntry bandStack[] = {
    {"160m",  1810000L,  2000000L,  1840000L},
    {"80m",   3500000L,  4000000L,  3700000L},
    {"60m",   5260000L,  5410000L,  5330000L},
    {"40m",   7000000L,  7300000L,  7150000L},
    {"30m",  10100000L, 10150000L, 10125000L},
    {"20m",  14000000L, 14350000L, 14250000L},
    {"17m",  18068000L, 18168000L, 18118000L},
    {"15m",  21000000L, 21450000L, 21250000L},
    {"12m",  24890000L, 24990000L, 24940000L},
    {"10m",  28000000L, 29700000L, 28500000L},
    // VHF and up. These are NOT in the touch UI's band-tile rows (which stay
    // HF — see BAND_SELECT below); they are here so that VFO→band tracking,
    // the band-name readout, and per-band lastHz memory all work when the
    // operator tunes up here. An IC-9700 is only ever in this part of the list.
    {"6m",   50000000L,  54000000L,  50150000L},
    {"2m",  144000000L, 148000000L, 144200000L},
    {"70cm",420000000L, 450000000L, 432100000L},
    {"23cm",1240000000L,1300000000L,1296100000L}
};
const int N_BANDS = sizeof(bandStack) / sizeof(bandStack[0]);

// ---------------------------------------------------------------------------
// Display
// ---------------------------------------------------------------------------
Arduino_H7_Video         Display(800, 480, GigaDisplayShield);
GigaDisplay_GFX          tft;
Arduino_GigaDisplayTouch Touch;
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
void loop() {
    discoveryTick();
    mdns.loop();
    wsTick();
    handleSerial();
    drainEncoder();
    keyerTick();
    encAutoReleaseTick();

    // Splash / persona menu owns the screen — bypass normal touch + draw
    // paths while it's up. Splash drives its own touch and countdown.
    if (g_splash.active) {
        splashHandleTouch();
        splashTick();
        return;
    }

    // Touch is cheap (GT911 I2C, ~5-10 ms) — always run so taps register
    // even when the keyer is mid-element. The earlier skip-during-keyer
    // version blocked iambic A/B chip taps whenever D4/D5 noise put the
    // state machine into a non-IDLE cycle.
    handleTouch();

    // Animate the 10m long-press wipe (no-op unless gestureActive).
    gestureWipeTick();

    // Drawing is the expensive one (~30-50 ms of GFX). Two paths:
    //   1. Explicit user action (uiNeedsRedraw flag set) → redraw NOW,
    //      regardless of keyer state. Operator just tapped a chip /
    //      band tile / iambic toggle and needs immediate visual
    //      confirmation. Worth the timing hit on this one element.
    //   2. Periodic refresh (every 250 ms) → only when keyer is
    //      fully idle so element boundaries above ~15 WPM aren't
    //      smeared by a redraw landing mid-element.
    static unsigned long lastDraw = 0;
    if (uiNeedsRedraw) {
        drawDynamic();
        lastDraw = millis();
        uiNeedsRedraw = false;
    } else if (kr.state == KS_IDLE && millis() - lastDraw > 250) {
        drawDynamic();
        lastDraw = millis();
    }
}

// ===========================================================================
// WiFi
// ===========================================================================
void wifiConnect() {
    // Status message goes into the splash's bottom strip — doesn't overlap
    // the persona buttons.
    //
    // ⛔ DO NOT ADD WiFi.end() / WiFi.disconnect() RETRY LOGIC HERE.
    //
    // An earlier version did exactly that — bounded wait, then cycle the radio
    // (disconnect/end → 3 s off → begin) on the theory that the Giga WiFi
    // "occasionally wedges on connect". A later build made it more aggressive
    // still, dropping the DHCP lease every attempt. The result, found on the
    // bench 2026-08-05: the pad reached **attempt 110+** and had never once
    // connected. Cycling the Giga's WiFi radio is not a recovery from the wedge
    // — it is a reliable way to CAUSE it.
    //
    // ⭐ The evidence is the amp simulator on the same bench, same network, same
    // board type, same SSID: it calls WiFi.begin() once, waits, and NEVER calls
    // WiFi.end() or WiFi.disconnect() anywhere in the sketch. It connects first
    // time, every time.
    //
    // So: begin() once, then wait patiently. Re-begin() only after a long
    // timeout, and still never tear the radio down. A control surface that
    // takes 30 s to appear after a power cut is fine; one that never appears
    // is not.
    const uint32_t kAttemptMs = 30000;   // 30 s of patience before re-begin()

    splashStatus("Connecting to WiFi...", C_CYAN);
    Serial.print("WiFi: ");

    uint16_t tries = 0;
    for (;;) {
        tries++;
        WiFi.begin(WIFI_SSID, WIFI_PASS);
        uint32_t t0 = millis();
        while (WiFi.status() != WL_CONNECTED && (millis() - t0) < kAttemptMs) {
            delay(400);
            Serial.print(".");
        }
        if (WiFi.status() == WL_CONNECTED) {
            Serial.println();
            Serial.print("WiFi connected, IP = "); Serial.println(WiFi.localIP());
            splashStatus("WiFi connected", C_GREEN);
            return;
        }

        // Still not up after 30 s. Say so, then simply ask again — no
        // disconnect(), no end(), no lease drop. The radio stays initialised,
        // which is the state it actually connects from.
        Serial.print(" attempt "); Serial.print(tries); Serial.println(" — still trying");
        splashStatus("WiFi: still trying...", C_AMBER);

        // ⚠ If this never succeeds, suspect the WiFi FIRMWARE rather than this
        // code: the Giga keeps its WiFi blob in external flash, and if that is
        // missing or corrupt every connect fails identically. The mbed stack
        // prints "Failed to mount the filesystem containing the WiFi firmware"
        // / "Please run the WiFiFirmwareUpdater sketch once". Watch the serial
        // console at boot for those before changing anything here.
    }
}

// ===========================================================================
// Discovery — UDP probe + reply listener, fallback to hardcoded host
// ===========================================================================
void discoveryTick() {
    if (st.hostKnown) return;
    unsigned long now = millis();

    // Probe every DISCOVERY_INTERVAL ms
    if (now - lastDiscoveryTx > DISCOVERY_INTERVAL) {
        lastDiscoveryTx = now;
        IPAddress bcast = WiFi.localIP();
        bcast[3] = 255;       // subnet broadcast (assumes /24)
        udp.beginPacket(bcast, DISCOVERY_PORT);
        udp.write((const uint8_t*)DISCOVERY_PROBE, strlen(DISCOVERY_PROBE));
        udp.endPacket();
        Serial.print("Discovery probe → "); Serial.println(bcast);
    }

    // Listen for reply
    int n = udp.parsePacket();
    if (n > 0) {
        char buf[128];
        int got = udp.read(buf, min(n, (int)sizeof(buf) - 1));
        buf[max(0, got)] = '\0';
        Serial.print("Discovery reply: "); Serial.println(buf);
        // Expected: "AETHERSDR ip=10.0.0.107 tci=40001"
        // IPAddress::fromString() rejects the trailing " tci=..." so we have
        // to chop the IP into its own NUL-terminated buffer first.
        char* ip = strstr(buf, "ip=");
        char* tp = strstr(buf, "tci=");
        if (ip && tp) {
            char ipBuf[20];
            const char* ipStart = ip + 3;
            const char* ipEnd   = strchr(ipStart, ' ');
            size_t ipLen = ipEnd ? (size_t)(ipEnd - ipStart) : strlen(ipStart);
            if (ipLen >= sizeof(ipBuf)) ipLen = sizeof(ipBuf) - 1;
            memcpy(ipBuf, ipStart, ipLen);
            ipBuf[ipLen] = '\0';

            IPAddress h;
            if (h.fromString(ipBuf)) {
                st.host = h;
                st.port = (uint16_t)atoi(tp + 4);
                st.hostKnown = true;
                uiNeedsRedraw = true;
                Serial.print("AetherSDR @ "); Serial.print(h);
                Serial.print(":"); Serial.println(st.port);
            } else {
                Serial.print("Discovery: bad IP '"); Serial.print(ipBuf); Serial.println("'");
            }
        }
    }

    // Fallback after timeout
    if (!st.hostKnown && !fallbackArmed && now - discoveryStarted > DISCOVERY_FALLBACK) {
        st.host = FALLBACK_HOST;
        st.port = FALLBACK_PORT;
        st.hostKnown = true;
        fallbackArmed = true;
        uiNeedsRedraw = true;
        Serial.print("Discovery timeout — falling back to ");
        Serial.print(st.host); Serial.print(":"); Serial.println(st.port);
    }
}

// ===========================================================================
// WebSocket TCI client (hand-rolled, like ShackController)
// ===========================================================================
void wsTick() {
    if (!st.hostKnown) return;
    // While in RC-28 TEST mode, the TCI socket is intentionally torn down
    // (see enterTestMode). Don't reconnect until the operator exits TEST.
    if (currentMode == AetherPadMode::Test) return;

    if (!tcp.connected()) {
        if (st.tciConnected) {
            st.tciConnected = false;
            wsHandshakeDone = false;
            wsRxBuf = "";
            uiNeedsRedraw = true;
            Serial.println("TCI: disconnected");
        }
        static unsigned long lastTry = 0;
        if (millis() - lastTry < 3000) return;
        lastTry = millis();
        wsConnect();
        return;
    }

    if (!wsHandshakeDone) return;   // still reading 101 response
    wsParseIncoming();
}
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

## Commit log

2026-05-09 Initial public release — aether_pad standalone AetherSDR controller
    Hardware control surface for AetherSDR running on Arduino Giga R1 WiFi
    + Giga Display Shield + optical encoder + 3.5 mm CW paddle jack. One
    self-contained desktop unit drives VFO, mode/volume/band, and an
    iambic keyer over AetherSDR's TCI WebSocket.
    Brought out of the private shack-experiments repo to its own public
    home for visibility. Code base:
    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
    [1.stl, Aether pad 180.stl, Aether pad top.stl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]
2026-05-09 Switch keyer to GPIO drive (D6) for bullet-proof CW timing
    WebSocket-over-WiFi keying via TCI keyer:0,true|false; was the v0.1
    default, but bench testing showed audible dit/dah length variance even
    at 20 WPM thanks to wireless latency + jitter — the hardware key line
    is the right path for anything timing-critical.
    Changes:
    • aether_pad.ino: KEY_PIN_OUT (D6) declared with the other key pins,
    pinMode/digitalWrite LOW set in setup() so the radio is never left
    keyed on boot, keyerOutput() now just toggles D6 directly.
    • Optional KEYER_TCI_ECHO compile-time flag (default 0): when set,
    the function additionally publishes the TCI keyer events for
    AetherSDR-side UI / sidet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
    [aether_pad.ino]
2026-05-11 Expand Building into a step-by-step Install section
    Walks through Arduino IDE install, board package, WiFi config, board /
    port selection, upload, and serial-monitor verification — plus a short
    troubleshooting list. Aimed at hams who don't live in the IDE every day.
2026-05-13 Advertise on mDNS as _tci._tcp.local (controller, aether-pad)
    Adds a small self-contained mDNS responder (mdns_tci.h/.cpp) that
    implements the schema from ten9876/AetherSDR docs/tci-discovery.md.
    aether_pad now announces itself on the LAN so AetherSDR's upcoming
    Peripherals browse — and tools like TCI Monitor — can list it
    without manual IP entry.
    class=controller, model=aether-pad, SRV port=0 (aether_pad is a
    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
2026-05-13 Move sketch + mDNS helpers into aether_pad/ subfolder
    Arduino IDE requires the sketch file to live in a folder of the
    same name (i.e. aether_pad/aether_pad.ino), otherwise it offers to
    move the .ino on open — which leaves mdns_tci.h/.cpp orphaned at
    the parent and breaks the compile.
    Pure file move; no source changes.
2026-05-13 Cache tile state to kill the BAND-button flicker
    drawDynamic() was unconditionally repainting all 10 bottom tiles
    every ~250 ms — fillRoundRect → drawRoundRect → label. The
    visible flicker on band buttons was the half-frame gap between
    the background clear and the label re-print.
    Add a per-tile (label, active) cache. drawTile() now only runs
    when something has actually changed; in steady state the loop
    short-circuits and the tile region is left untouched. Cache is
    invalidated explicitly from drawStatic() so a full-screen wipe
    still forces a clean repaint on the next dynamic pass.
    No behavioural change beyond the removed flicker — band-change
    highlight, mode tray switch, KEYER-tr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
    [aether_pad.ino]
2026-05-20 case: add iso-top-right render + STEP for "aether pad case split"
    Adds a 1600x1200 PNG hero render (iso-top-right) and a STEP export of
    the two-body shelled-and-split enclosure (case bottom + lid). STL was
    also re-exported (byte-identical to the existing one, no diff).
    [aether pad case split.step]
2026-05-20 feat(rc28): Phase A — USB HID device enumerated as Icom RC-28
    Adds an mbed-os PluggableUSBHID subclass impersonating the Icom RC-28
    tuning controller for hardware-in-the-loop testing of AetherSDR PR
    ten9876/AetherSDR#2870. Identifies as VID 0x0C26 / PID 0x001E / bcd 0x0100.
    Report layout (32 bytes payload + 1 byte Report ID = 33 wire bytes per
    report) matches the CORRECTED layout in PR #2870:
    data[0] seq counter (0x01 or 0x02; parser acts on 0x01 only)
    data[1] unused
    data[2] direction (0x00 idle / 0x01 CW / 0x02 CCW)
    data[3] unused
    data[4] buttons (idle=0x07 / F1=0x05 / F2=0x03 / TX=0x06)
    data[5..31] zero
    The class is enumerated at boot but silent in NORMAL operation — no
    r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
    [aether_pad.ino]
2026-05-21 feat(rc28): Phase B/C/D — TEST mode with wipe-to-confirm gesture + 6 stimuli
    Adds the full RC-28 emulator test bench on top of the Phase A HID device.
    State machine: NORMAL ──[10m long-press]──▶ TEST ──[Return tap]──▶ NORMAL
    Entry gesture (on the 10m band tile):
    - Single tap: normal band-change behaviour preserved (unchanged UX)
    - Held past 200ms dead-zone: red-curtain wipe animates left-to-right
    across the 800px screen over ~1300ms
    - Curtain reaches right edge (~1500ms total): commits to TEST mode,
    disconnects TCI, swaps to test screen
    - Released before commit: gesture aborts, normal UI repaints
    TEST screen:
    - Top red banner "TEST MODE - TCI DISCONNECTED"
    - St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
    [aether_pad.ino]
2026-05-21 fix(rc28): exitTestMode now does a full repaint, not just drawDynamic
    Found during the first end-to-end test on Giga R1 (2026-05-20 evening):
    tapping Return in TEST mode left the test banner / status line / button
    grid partially showing through over the normal UI. Root cause:
    exitTestMode only set uiNeedsRedraw=true, which causes the main loop to
    call drawDynamic() — which only paints dynamic regions, not the full
    layout.
    Fix: explicitly call drawStatic() (does fillScreen + rebuilds the chip
    + band-tile + freq display layout) followed by drawDynamic() (live
    values) from exitTestMode, then clear uiNeedsRedraw. Same pattern as
    enterTestMode which calls drawTestStatic + drawTestDynamic.
    Co-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
    [aether_pad.ino]
2026-05-25 feat(persona): boot splash + 3-button persona menu
    Extends AetherPadMode with NormalTci / NormalRc28 / NormalAetherControl
    as siblings to the existing Test mode. exitTestMode now restores the
    persona that was active before TEST was entered (via g_prevPersonaMode)
    so the operator returns to wherever they came from rather than always
    landing on Normal.
    Splash drawn immediately at boot with title + 3 persona buttons + 3 s
    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
2026-05-25 docs: add device photos + README gallery section
    Two photos of the working hardware in its red 3D-printed case: the
    boot splash showing the persona menu (TCI / RC-28 / AetherControl
    buttons + auto-continue countdown), and the TCI persona's operator
    screen tuned to 28.500.000 USB on 10 m.
    Photos stored under docs/images/ and referenced in a new Gallery
    section at the top of README.md.
2026-05-25 feat(persona): re-skin operator UI with per-persona accent + pill badge
    Phase 1 of the persona visual-distinction work. Each Normal* persona's
    operator screen now reads in its own accent colour so a glance tells the
    operator which page they're on:
    TCI → cyan (existing default, unchanged behaviour)
    RC-28 → amber
    AetherControl → green
    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
2026-05-25 feat(persona): dedicated operator screens for RC-28 + AetherControl
    Phase 2 + 3 of the persona work — each persona now has its own dedicated
    layout (parallel to TEST), not just a recoloured TCI screen. drawStatic
    and drawDynamic dispatch to per-persona renderers based on currentMode.
    RC-28 persona (amber):
    - Big amber frequency band across the top (echoes st.freqHz for now)
    - Three operator buttons in a row: F1, F2, TX (TX red-tinted so the
    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
2026-05-25 feat(usb): Phase 4a — add second CDC endpoint for AetherControl protocol
    The Giga is already a composite USB device (HID for RC-28 + CDC for the
    default Serial Monitor). Adding a second arduino::USBSerial instance
    ('actrlSerial') gives the host a *second* virtual COM port that's ours
    to drive without contaminating the existing Serial Monitor stream.
    For now this is plumbing only — Phase 4c will layer the FlexControl-
    compatible protocol on top (D;/U;/X1S;/S; out for events, I100;/I010;/
    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
2026-05-25 Revert "feat(usb): Phase 4a — add second CDC endpoint for AetherControl"
    This reverts commit d08c646.
    Reason: hardware test 2026-05-25 showed mbed_giga 4.5.0's PluggableUSB
    framework only exposes ONE composite CDC interface, regardless of how
    many `arduino::USBSerial` instances we construct. Both `Serial` and our
    `actrlSerial` ended up writing to the same COM3 endpoint (proven by the
    heartbeat AND debug-Serial output interleaving on the host's single port).
    So the "second virtual COM port for AetherControl protocol" approach is
    not achievable without modifying the mbed core or pivoting to a vendor-
    specific HID endpoint. Path A picked instead: use the existing single
    CDC, and gate noisy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
    [aether_pad.ino]
2026-05-31 fix(wifi): self-recover from Giga WiFi wedge instead of hanging forever
    wifiConnect() was an infinite blocking spin-wait (while status != CONNECTED)
    with no timeout or retry, so when the Giga R1 WiFi wedged on connect the
    firmware hung and the only recovery was a physical reset. Replace with a
    bounded per-attempt wait (12 s) and, after 3 failures, a radio power-cycle
    (disconnect/end then 3 s off then begin), looping forever with on-screen
    status. A headless control surface now gets itself back online after a power
    blip with no manual intervention.
    Also: README note to pin Arduino_GigaDisplay_GFX to 1.0.0 (1.1.0 black-screens
    the display against the stable Mbed Giga core's bundled Arduino_H7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
    [aether_pad.ino]
2026-08-05 fix(wifi): stop cycling the radio — that WAS the wedge, not the cure
    The pad was never reconnecting slowly. It was never connecting at all: found on
    the bench at attempt 110+, looping "failed; dropping lease, waiting 5s" forever,
    on the same SSID and the same network where the amp-simulator Giga connects
    first time every time.
    The retry logic was the cause. It waited 12 s, then tore the radio down
    (disconnect + end + 3 s off) and began again -- added on the theory that the
    Giga WiFi "occasionally wedges on connect". Cycling the Giga's WiFi radio is not
    a recovery from that wedge; it is a reliable way to cause it. The flashed build
    was more aggressive still, dropping the DHCP lease every a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
    [aether_pad.ino]
2026-08-05 fix(discovery): correct the fallback endpoint — .107:40001 was stale twice over
    The pad's hardcoded fallback pointed at 10.0.0.107:40001. Both halves were
    wrong: .107 is a pre-DHCP address aurora13 no longer holds, and AetherSDR
    listens on 50001, not the 40001 in the older notes. Verified live before
    changing it — ws://10.0.0.104:50001 answers a TCI `start;` with vfo_limits and
    trx_count.
    ⚠ The fallback was not actually the reason the pad could not reach AE, and it is
    worth recording why. A discovery responder on the Aether-gate Pi5 (10.0.0.128),
    running since 7 July, was answering the pad's UDP probe with
    "AETHERSDR ip=10.0.0.128 tci=40001" — an endpoint that does not exist, becaus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
    [aether_pad.ino]
2026-08-05 fix(volume): send dB not percent, and stop the radio's echo overwriting the knob
    Two bugs, one symptom: the volume swept from silent to full within a couple of
    detents and then read 100 whatever you did.
    ⛔ TCI `volume:` IS dB (-60..0), NOT PERCENT. The pad sent its 0-100 UI value
    straight out; AetherSDR clamps to [-60, 0], so EVERY value above 0 became 0 dB =
    full volume. Only the very bottom of the knob's travel did anything. Verified
    against the live radio rather than assumed: AE answers `volume;` with `volume:0`
    at full audio and converts with TciProtocol::volumeDbFromPercent(), which is
    20*log10(pct/100) clamped to [-60, 0]. The pad now mirrors that function exactly,
    so its 0-100 UI l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
    [aether_pad.ino]
2026-08-05 feat(ui): release the VOLUME and MODE chips when the operator is done with them
    An armed chip meant the NEXT nudge of the knob did something unintended — a
    nudge meant for the VFO changed the audio instead, because VOLUME was still
    holding the encoder from minutes earlier. The knob should rest on the VFO.
    MODE releases the moment a mode is picked from the tray: choosing one IS the
    finish, and there is nothing further to do with the encoder afterwards.
    VOLUME has no natural finishing action — you stop turning and walk away — so a
    2 s idle timer stands in for one. The timer resets on every detent, so it cannot
    fire mid-adjustment however slowly the knob is turned.
    Both reuse the exist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
    [aether_pad.ino]
2026-08-06 feat(bands): reach VHF/UHF/SHF — lift the 60 MHz ceiling and add 6m/2m/70cm/23cm
    The pad could not tune above 60.000 MHz. The knob simply stopped there, which
    made it useless against a VHF/UHF radio — an IC-9700 lives ENTIRELY above that
    limit (2 m / 70 cm / 23 cm), so not one of its bands was reachable.
    FOUR separate faults, three of them the same hardcoded assumption:
    1. cmdVfoDelta() clamped to 60000000UL.
    2. The serial console's `freq` command clamped to 60000000L independently, so
    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
